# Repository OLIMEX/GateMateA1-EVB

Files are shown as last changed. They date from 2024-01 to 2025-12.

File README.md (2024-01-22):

# GateMateA1-EVB
Development board for GateMateA1 CCGM1A1 FPGA from Cologne Chip with PS2 VGA 64Mbit RAM RP2040

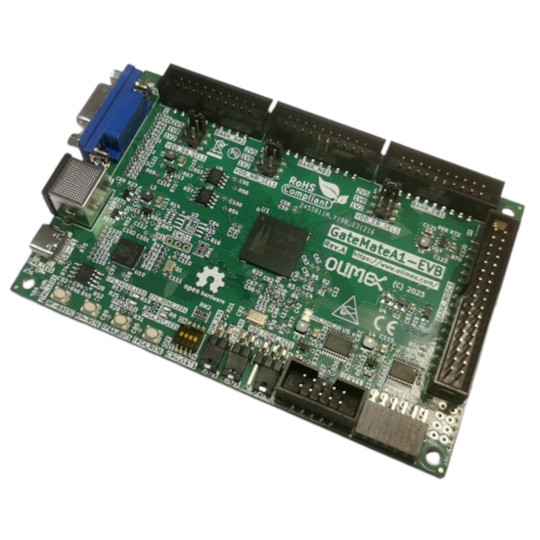
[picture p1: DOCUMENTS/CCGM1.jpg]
CCGM1


https://www.olimex.com/Products/FPGA/GateMate/GateMateA1-EVB/open-source-hardware

Features:

* CCGM1A1 FPGA with 20480 logic cells
* PSRAM 64Mbit
* RP2040 processor for prograaming and debugging
* 2MB configuration Flash
* 4 buttons
* USB-C for power supply and programming
* PS2 connector
* VGA connector
* 4 Banks with signals with selectable levels 1.2V 1.8V 2.5V
* PMOD with level shifters
* UEXT with level shifters
* Power LED
* User LED
* 4 sections configuration slide switch
* Dimensions: 120 x 80 mm

## Licenses

* Hardware is released under CERN Open Hardware Licence Version 2 - Strongly Reciprocal, all silkscreen credits to Olimex should remain;
* Software is released under GPL3 Licensee
* Documentation is released under CC BY-SA 3.0

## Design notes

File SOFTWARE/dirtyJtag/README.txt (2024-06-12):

dirtyJtag.uf2 is the binary we load on every GateMateA1-EVB,
it allows to program the board via tools like openFPGALoad

Notice! By default, on a brand-new device you don't need to perform the steps below,
they are listed just as information or in case you overwrote the pico-dirtyJtag!

If you have overwritten it, you can find the binary here to restore it.

1. To download dirtyJtag.uf2, first put RP2040 in bootloader mode:

Press and hold button RP-BOOT1, press and release RP-RST1, release button RP-BOOT1.

2. New storage device will appear. 

3. Copy-paste dirtyJtag.uf2 on the storage device, this will make the storage disappear 
and after few moments DirtyJTAG device would appear.

4. All done. Now you can use the openFPGAload.

This dirtyJtag.uf2 binary is made using pico-dirtyJtag project:

https://github.com/phdussud/pico-dirtyJtag

Which itself is made after DirtyJTAG project:

https://github.com/dirtyjtag/DirtyJTAG

This binary inherits any license by the original projects, make sure to respect
the licensing of the pico-dirtyJtag and DirtyJTAG projects.

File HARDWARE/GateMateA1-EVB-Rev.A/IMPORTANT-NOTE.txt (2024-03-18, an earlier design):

GateMateA1-EVB shipped before March 1st 2024 are affected by high ripple voltage on VDD_PLL which create problems.
Small batch of GateMateA1-EVB was assembled with R5 value of 1.3 ohm which do not provide enough filtering of the VDD_PLL power supply.
Increasing R5 to 22 ohm solves the issue. Around 40 boards were shipped to customers before this issue was reported and fixed. All boards shipped after February 29th are fixed and do not have such problem.

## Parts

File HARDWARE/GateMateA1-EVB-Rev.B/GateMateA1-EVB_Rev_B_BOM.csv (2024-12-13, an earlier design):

Quantity | Value | Footprint | Reference
3 | B-V-20-LF | GBH-254-SMT-20 | BANK_EB1, BANK_NA1, BANK_NB1
1 | B-V-34-LF | GBH-254-SMT-34 | BANK_MISC1
18 | 2.2uF/6.3V/20%/X5R/C0402 | C_0402_5MIL_DWS | C1, C2, C3, C4, C5, C6, C7, C8, C43, C47, C58, C62, C66, C68, C73, C78, C106, C107
41 | 100nF/10V/20%/X5R/C0402 | C_0402_5MIL_DWS | C9, C10, C11, C12, C13, C14, C15, C16, C30, C42, C44, C46, C48, C59, C63, C67, C70, C75, C82, C85, C86, C87, C88, C89, C90, C91, C92, C94, C95, C96, C97, C98, C99, C100, C101, C102, C103, C104, C105, C108, C109
45 | 1nF/50V/10%/X7R/C0402 | C_0402_5MIL_DWS | C17, C18, C19, C20, C21, C22, C23, C24, C25, C26, C27, C28, C29, C31, C32, C33, C34, C35, C36, C37, C38, C41, C45, C49, C50, C51, C52, C53, C54, C55, C56, C57, C60, C61, C64, C65, C69, C71, C72, C74, C76, C77, C79, C80, C81
3 | 10uF/6.3V/X5R/20%/C0402 | C_0402_5MIL_DWS | C39, C40, C126
6 | 22uF/6.3V/20%/X5R/C0603 | C_0603_5MIL_DWS | C83, C112, C114, C118, C120, C124
2 | 18pF/50V/5%/C0G/C0402 | C_0402_5MIL_DWS | C110, C111
5 | 47uF/6.3V/20%/X5R/C0805 | C_0805_5MIL_DWS | C113, C115, C119, C121, C125
2 | LED/GREEN/0603 | LED_0603_KA | CFG_DONE_LED1, FPGA_LED1
3 | LED/RED/0603 | LED_0603_KA | CFG_FAILED_LED1, FPGA_RST_LED1, PWR_LED1
1 | DSHP04TS-S | DSHP04TS-S-1.27mm_Half_4_Slide | CFG_SET1
2 | H-WX-1x2-LF(Closed) | HN1x2(SMD)_H-WX-1x2-LF | CLK0_EN1, POR_EN1
1 | Q10MHz/30ppm/1.62V-3.63V/4P/5x3.2mm(SX5M10.000M20F30TNN_LCSC-C2901522) | 5032-4P_HCX-3S | CR1
1 | 1N5819S4/SOD123 | SOD-123_1C-2A_KA | D1
2 | BSS138(SOT-23-3) | SOT23 | FET1, FET2
4 | YTS-A016-X | YTS-A016-X | FPGA_BUT1, FPGA_RST1, RP-BOOT1, RP-RST1
1 | LED/YELLOW/0603 | LED_0603_KA | JTAG_LED1
6 | MJ6 | MJ6 | JUMP_CAP1, JUMP_CAP2, JUMP_CAP3, JUMP_CAP4, JUMP_CAP5, JUMP_CAP6
2 | FB0805/600R/2A | L_0805_5MIL_DWS | L1, L2
5 | 1.0uH/2.5A/DCR=30mR/20%/3.00x3.00x1.50mm/CD32(SWPA3015S1R0MT) | CD32 | L3, L4, L5, L6, L7
1 | MDR6_MINI-DIN | PS2_MDR6_MINI-DIN | PS2_KBD1
1 | F-R-2x06-LF | Digilent_Pmod_12-pin | Pmod1
1 | Q12MHz/20pF/10ppm/4P/3.2x2.5mm | TSX-3.2x2.5mm_GND(3) | Q1
4 | 0R/R0402 | R_0402_5MIL_DWS | R2, R3, R6, R10
1 | 4.7R/R0402 | R_0402_5MIL_DWS | R5
8 | 2.2k/R0402 | R_0402_5MIL_DWS | R7, R17, R18, R25, R26, R27, R66, R76
10 | 10k/R0402 | R_0402_5MIL_DWS | R8, R19, R23, R24, R28, R29, R30, R45, R53, R57
6 | 100R/R0402 | R_0402_5MIL_DWS | R20, R36, R46, R50, R51, R59
1 | 200R/1%/R0402 | R_0402_5MIL_DWS | R22
3 | 22R/R0402 | R_0402_5MIL_DWS | R31, R54, R58
3 | 430R/1%/R0402 | R_0402_5MIL_DWS | R32, R37, R41
3 | 866R/1%/R0402 | R_0402_5MIL_DWS | R33, R38, R42
3 | 2.05k/1%/R0402 | R_0402_5MIL_DWS | R34, R39, R43
3 | 4.42k/1%/R0402 | R_0402_5MIL_DWS | R35, R40, R44
2 | 27R/R0402 | R_0402_5MIL_DWS | R55, R56
1 | 3.32k/1%/R0402 | R_0402_5MIL_DWS | R60
1 | 4.7k/1%/R0402 | R_0402_5MIL_DWS | R61
4 | 100k/R0402 | R_0402_5MIL_DWS | R62, R63, R69, R70
2 | 1.05k/1%/R0402 | R_0402_5MIL_DWS | R64, R65
1 | 20k/1%/R0402 | R_0402_5MIL_DWS | R67
3 | 10k/1%/R0402 | R_0402_5MIL_DWS | R68, R71, R72
1 | 1k/1%/R0402 | R_0402_5MIL_DWS | R73
2 | 5.1k/1%/R0402 | R_0402_5MIL_DWS | R74, R75
1 | 6.04k/1%/R0402 | R_0402_5MIL_DWS | R77
1 | 2k/1%/R0402 | R_0402_5MIL_DWS | R78
1 | 3.01k/1%/R0402 | R_0402_5MIL_DWS | R79
2 | RA1206_(4x0603)_4B8_10k | RA1206_(4X0603)_4B8_xx | RM1, RM2
1 | CCGM1A1(FBGA-324) | FBGA-324_P0.8mm_Pad0.4mm_Ball0.45mm_Dim15.00x15.00x1.20mm | U1
1 | HX7027(SOT-23-3) | SOT-23 | U2
2 | TXB0108PWR(TSSOP-20) | TSSOP20_Pitch-0.65mm_6.6x4.5x1.2mm | U5, U6
2 | LY68S3200SLT(SOIC-8_150mil) | SOIC-8_150mil | U7, U9
1 | ZD25WQ16CSIGT(SOIC-8_208mils) | SO-8_208mil | U8
1 | RP2040(QFN-56_7x7mm_P0.4mm) | QFN56_7x7_Pitch_0.4mm | U10
5 | TPS62A02ADRLR(SOT-563-6) | SOT-563-6 | U11, U12, U13, U14, U15
1 | P-B-V-10-LF | GBH-254-SMT-10 | UEXT1
1 | USB-C-16P-F(A40-00119-A52-12) | USB2.0_TYPE-C(A40-00119-A52-12)_Paste | USB-C1
1 | H-WX-1x3-LF(1-2:Closed/2-3:Opened) | HN1x3(SMD)_H-WX-1x3-LF | VDD_CORE_SET1
3 | H-V33X-2x03-LF(1-2:Closed) | GPH254SMT02x03(H-V33X-2X3-LF) | VDD_EB_SEL1, VDD_NA_SEL1, VDD_NB_SEL1
1 | HDR15-3.08-14.5T/VGA15/14.5mm | VGA15-F(HDR15-3.08-14.5T)_DrillSlot | VGA1

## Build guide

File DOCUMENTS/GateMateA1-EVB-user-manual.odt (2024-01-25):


GateMateA1-EVB

User Manual

Rev.1.0 January 2024 olimex.com

# What is Cologne Chip GateMateA1

The GateMateTM FPGA family of Cologne Chip AG addresses all application requirements of small to medium size FPGAs. Logic capacity, power consumption, package size and PCB compatibility are best in class. GateMateTM FPGAs combine these features with lowest cost in industry making the devices well suited from University projects to high volume applications. Because of the outstanding circuit size/cost ratio, new applications now can use the benefits of FPGAs.

All this is based on a novel FPGA architecture combining CPE programmable elements with a smart routing engine. The CPE architecture allows an efficient building of arbitrarily-sized multipliers. Memory aware applications can use block RAMs with bit widths of 1 to 80 bits.

General Purpose IOs (GPIOs) can use different voltage levels from 1.2 to 2.5 Volt. All GPIOs can be configured as single-ended or LVDS differential pairs. Furthermore a high speed SerDes interface is available.

FPGA designs are synthesized using the Yosys framework. The free Cologne Chip P&R-software generates the FPGA bitstream.

A Static Timing Analysis (STA) is also performed and gives evidence about critical paths and the overall performance of a design. The design can be simulated using Verilog netlist and SDF timing extraction.

The devices are manufactured using GlobalfoundriesTM 28 nm SLP (Super Low Power) process. Due to manufacturing in Europe, there is no danger of trade restrictions or high taxation.

CCGM1A1 has these features:

- Logic Cells 20,480 CPE correspond to: 20,480 8-Input-LUT trees or, 40,960 4-Input-LUT trees with 40,960 FF/Latches
- Block RAM Total 1,280 Kb: 20Kb blocks: 64, 40Kb blocks: 32
- PLLs 4
- SerDes 5 Gb/s 1
- I/Os single-ended: 162, differential: 81, 1.2V to 2.5V, double data rate (DDR) support
- Performance Modes Low Power, Economy, Speed (0.9V – 1.1V)
- Package 324 balls 0.8mm fine pitch ball grid array (FBGA), 15x15 mm

## GateMateA1-EVB features:

- CCGM1A1 FPGA with 20480 logic cells
- PSRAM 64Mbit
- RP2040 processor for programing and debugging
- 2MB configuration Flash
- 4 buttons
- USB-C for power supply and programming
- PS2 connector
- VGA connector
- 4 Banks with signals with selectable levels 1.2V 1.8V 2.5V
- PMOD with level shifters
- UEXT with level shifters
- Power LED
- User LED
- 4 sections configuration slide switch
- Dimensions: 120 x 80 mm

## Order codes for GateMateA1-EVB:

GateMateA1-EVB (https://www.olimex.com/Products/FPGA/GateMate/GateMateA1-EVB/open-source-hardware) commercial grade -40+85C board with internal antenna

USB-CABLE-A-TO-C-1M (https://www.olimex.com/Products/Components/Cables/USB-CABLE-A-TO-C-1M/) USB-C cable

UEXT modules (https://www.olimex.com/Products/Modules/) - different sensors, relays, LCDs, RTC, GSM, GPS etc accessories which can be connected to UEXT connector

# HARDWARE

## GateMateA1-EVB layout:


VGA

PS2

USB-C power/debug

UEXT

PMOD

NA bank

NB bank

EB bank

MISC connector

Core voltage select 0.9-1.0-1.1V

FPGA oscillator enable

POR enable

Configuration mode

RP2040 BOOT

RP2040 RST

FPGA button

FPGA RST

PSRAM

FPGA

## GateMateA1-EVB GPIOs:

NA

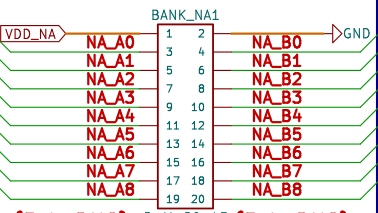
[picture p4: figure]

NB

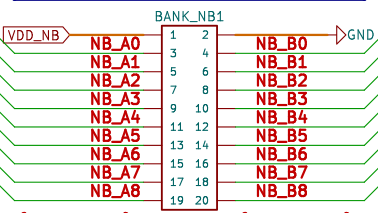
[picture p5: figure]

EB

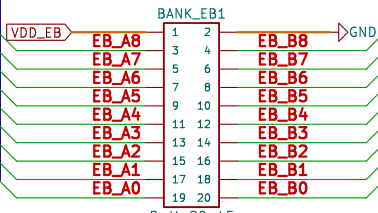
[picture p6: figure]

MISC

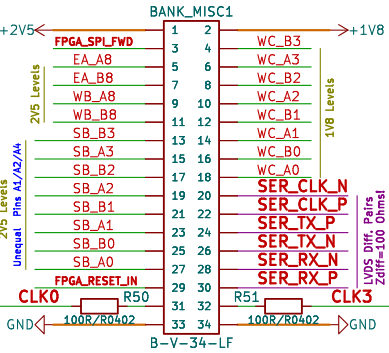
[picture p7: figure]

UEXT and PMOD

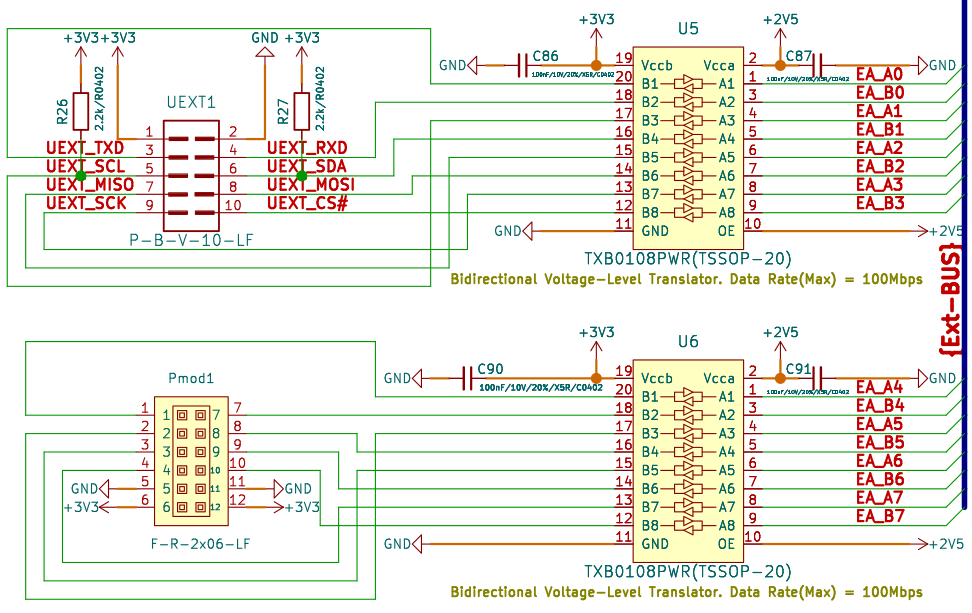
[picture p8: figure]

## GateMateA1-EVB schematics:

GateMateA1-EVB (https://www.olimex.com/Products/FPGA/GateMate/GateMateA1-EVB/open-source-hardware) latest schematic is on GitHub (https://github.com/OLIMEX/GateMateA1-EVB/blob/main/HARDWARE/GateMateA1-EVB-Rev.A/GateMateA1-EVB_Rev_A.pdf)

## GateMateA1-EVB power supply:

# (https://www.olimex.com/Products/Retro-Computers/AgonLight2/open-source-hardware)

GateMateA1-EVB (https://www.olimex.com/Products/FPGA/GateMate/GateMateA1-EVB/open-source-hardware) can be powered by USB-C connector.

The Core voltage can be changed between: 0.9-1.0-1.1V

The bank power supply can be selected between 1.2-1.8-2.5V

UEXT and PMOD are with 3.3V voltage levels.

## UEXT connector:

UEXT connector stands for Universal EXTension connector and contain +3.3V, GND, I2C, SPI, UART signals.

UEXT connector can be in different shapes.

The original UEXT connector is 0.1” 2.54mm step boxed plastic connector. All signals are with 3.3V levels.

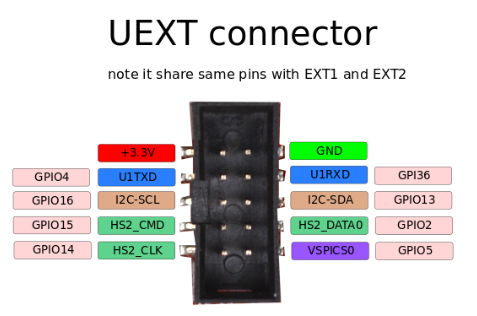
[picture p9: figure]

Olimex has developed number of MODULES (https://www.olimex.com/Products/Modules/) with this connector. There are temperature, humidity, pressure, magnetic field, light sensors. Modules with LCDs, LED matrix, Relays, Bluetooth, Zigbee, WiFi, GSM, GPS, RFID, RTC, EKG, sensors and etc.

# SOFTWARE:

Cologne Chip: Toolchain (https://github.com/OLIMEX/GateMateA1-EVB/blob/main/SOFTWARE/ug1002-toolchain-install-latest.pdf)Installation guide (https://github.com/OLIMEX/GateMateA1-EVB/blob/main/SOFTWARE/ug1002-toolchain-install-latest.pdf)

RP2040 firmware: pico-dirty-jtag (https://github.com/phdussud/pico-dirtyJtag)

Cologne Chip example: Logic Analizer (https://github.com/colognechip/gatemate_ila)

# Revision History

Revision 1.0 January 2024

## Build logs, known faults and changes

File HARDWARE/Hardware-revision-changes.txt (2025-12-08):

Hardware revision C
=====
1. L3,L4,L5,L6 and L7 changed to 1.0uH/4.2A/DCR=35mR/20%/2.00x1.60x1.00mm/L2016(PIM201610-1R0MTS00)

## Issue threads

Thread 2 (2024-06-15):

Tried the blink sample from Gatemate and it dows not blink, but LED gets on

lollisoft, 2024-06-15:
Hi,

after going through the documentation from FPGA vendor, I was able to syntethize the blink sample and with a small fix to build into the run script a version to address -b dirtyJTag and it loaded the bit file well.

But it does not blink. What happens, is that the green LED starts lighting above the reset LED.

First, I am a newby and don't have looked at the iverilog simulation by trusting blindly at first :-)

Is that a known issue?

Is it indeed blinking but too fast - what I cannot see?

Next I'll try to see any GTK waveform...

Thanks

Lothar

Closed 2024-06-16.

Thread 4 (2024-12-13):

GateMateA1-EVB_Rev_A.pdf still shows R5=1.3 Ohms

Andy2No, 2024-12-13:
In the schematic in PDF form, GateMateA1-EVB_Rev_A.pdf https://github.com/OLIMEX/GateMateA1-EVB/blob/main/HARDWARE/GateMateA1-EVB-Rev.A/GateMateA1-EVB_Rev_A.pdf, the value of R5 is still shown as 1.3 Ohms, despite that having to be revised to 22 Ohms to reduce PLL voltage ripple, as noted in IMPORTANT-NOTE.txt https://github.com/OLIMEX/GateMateA1-EVB/blob/main/HARDWARE/GateMateA1-EVB-Rev.A/IMPORTANT-NOTE.txt

There doesn't appear to be an updated version of that PDF, with the correct value.

TsvetanUsunov, 2024-12-13:
Thanks for pointing this out.
The 22 ohm is not good value either.
Our people forgot to update the board revision Rev.B changes which we ship now
I just updated it. The correct value for R5 is 4.7 ohm

Closed 2024-12-13.

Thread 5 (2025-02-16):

UEXT Level Shifted I2C not working

playduck, 2025-02-16:
I've been unable to get I2C working via the built-in level shifters.
When routing the I2C to pins without the level-shifters everything works (verified on HW with a logic analyzer).

However routing and measuring them via the dedicated `UEXT_{SCL,SDA}` pins (pictured) fails and results in completely mangled signals.

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

I'm creating the open-drain I2C signals via inferred TOBUFs and IOBUFs.
I've tried enabling PULLUPs in the ccf and external pullups (via an Analog Discovery).
On other `UEXT_` pins I haven't been able to get any output (with or without pullups).

I'm using a `Rev A` board.

The [`TXB0108PWR` datasheet](https://www.ti.com/lit/ds/symlink/txb0108.pdf) Section 7.3.5 states, that
> If pullup or pulldown resistors are connected externally to the data I/Os, their values must be kept higher than 50 kΩ to ensure that they do not contend with the output drivers of the TXB0108. For the same reason, the TXB0108 should not be used in applications such as I2C or 1-Wire where an open-drain driver is connected on the bidirectional data I/O. For these applications, use a device from the TI TXS01xx series of level translators.

The resistors `R26` and `R27` are only 2.2kΩ.

**I'm not sure if I'm doing something wrong or if the hardware for I2C is wrong.
Has anyone gotten I2C working at the `UEXT` port?**

I'm using [this I2C Master Core by Scott Larson](https://forum.digikey.com/t/i2c-master-vhdl/12797) with minor fixes, such that it compiles with GHDL (namely replacing `case` construct in line 88 with an `if/elsif/else` tree).

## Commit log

2024-01-22 initial upload
    [GateMateA1-EVB_Rev_A-B_Cu.gbr, GateMateA1-EVB_Rev_A-B_Mask.gbr, GateMateA1-EVB_Rev_A-B_Paste.gbr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]
2024-12-13 update revision B
    [GateMateA1-EVB_Rev_B-B_Cu.gbr, GateMateA1-EVB_Rev_B-B_Mask.gbr, GateMateA1-EVB_Rev_B-B_Paste.gbr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]
2026-02-16 Update
    Blinking LED binary and configs.
